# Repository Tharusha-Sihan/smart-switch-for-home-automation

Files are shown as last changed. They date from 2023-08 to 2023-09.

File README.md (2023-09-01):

# Smart Switch for Home Automation
This is an ESP32-based smart switch project designed to address the requirement for a convenient method to automate regular home appliances, especially in compact spaces like individual rooms. 

<p align="center">

</p>

## Reqirements
The followings were considered as the basic needs that should be satisfied by the solution.
  +	Should be able to control remotely.
  +	Should be compatible with existing home appliances.
  +	Should be able to install easily.
  +	Compatible with industry standards.
  +	Durable and reliable.
  +	should be cost effective.
  
In addition to that following features were intended to be integrated.
  +	Device can be controlled manually as well as remotely through internet and physical buttons.
  +	The device can be connected to any Wi-Fi network without hard coding. Which is a necessity for a consumer IoT device.
  +	Fits into the conventional sunk boxes and can be powered using domestic AC supply.
  +	Can control multiple appliances from one device.
  +	Users can connect the device to a new Wi-Fi network, switch appliances, set timers and monitor using a web interface or mobile app.
  
## Implementation
Considering its in-built WiFi connectivity, impressive processing power and the memory capacity, ESP32 microcontroller is selected as the central control unit of this embedded IoT project. Inbuild capacitive touch sensors of ESP32 were utilized as physical touch buttons. the design files of first prototype can be accessed in [version-01 folder.](version-01/)

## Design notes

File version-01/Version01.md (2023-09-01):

# version- 01
<p  float="left">
  
  
  </p>

## Block Diagram
<p  align="center">

</p>

## component selection
After comparing several alternatives, the following components were selected. Their performance, price, availability and reliability were mainly concerned.
+ **ESP32 WROOM 32D :** The ESP32 microcontroller is chosen for its processing capabilities and built-in WIFI connectivity. It offers sufficient computing power to manage the device and efficiently transmit data to the servers. Moreover, the ESP32’s ability to connect with nearby WIFI access points allows for seamless web integration. [Datasheet](https://www.mouser.com/datasheet/2/891/esp-wroom-32_datasheet_en-1223836.pdf)
+ **HLK-PM-03 :** To convert 230V AC supply into 3.3V DC HLK-PM-03 module is chosen due to its compact size, versatility, high reliability, energy efficiency, and ease of integration. This module boasts a remarkably small form factor, making it an ideal choice for space-constrained applications. It is designed for high energy efficiency which aligns perfectly with our goals.[Datasheet](https://datasheet.lcsc.com/szlcsc/1909111105_HI-LINK-HLK-PM24_C399250.pdf)
+ **Mechanical relays :** Despite the relatively low reliability compared to the solid-state relays mechanical relays were chosen due to their low cost.
+ **BS170 :** n-channel MOSFET is chosen for switching relays. It has a high current capacity.[Datasheet](https://www.onsemi.com/pdf/datasheet/mmbf170-d.pdf)
+ **Pull-up Resistors and Capacitors :** The selected pull-up resistors and capacitors are determined based on the ESP32 chip’s data sheet to ensure proper communication and programming.

### BoM
  
| Component | Quantity |
| --- | ---|
| ESP32 WROOM 32d | 1 |
|HLK-PM-03 | 1 |
|SRD 3V relay | 3 |
|Varistors 180pF 560volts 10% | 1 |
|Safety Capacitors 275VAC 0.1uF |	1 |
|BS170 n-channel MOSFET	|3|
|push buttonn |	2|
|10kOhm resistors 0805 pkg|	5|
|10uF - tantalum - 3216 mm	|1|
|0.1uF - 0805 pkg	|1|
|220uF - electrolyte|	1|
|100uF (extra) electrolyte|	1|
|1kOhm resistors 0805 pkg	|3|
|3ways terminal blocks 5.08 pitch|	1|
|2 ways terminal block 5.08 pitch|	1|
|3 pin JST connectors|	1|
|4 pin male headers|	1|

## Schematic Design
<p align="center">


</p>

## PCB Layout
<p align="center">

</p>

### Top Layer
<p align="center">
<img width ="55%" src=https://github.com/Tharusha-Sihan/smart-switch-for-home-automation/assets/116502446/feddea3c-755d-482b-a493-c083f2a8d2b6"/>
</p>

### Bottom Layer
<p align="center">

</p>

## Enclosure
Initial enclosure design is as follows. 
<p align="center">

</p>

After considering expandability, manufacturability and esthetics aspects initial designs were revised.

<p float="left">


</p>

## Interface
The user interface is designed with a seamless blend of touch buttons for manual control and a user-friendly web page for remote access and network configuration. 
<p align="center">

</p>

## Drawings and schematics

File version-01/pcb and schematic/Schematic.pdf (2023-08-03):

# Power Supply

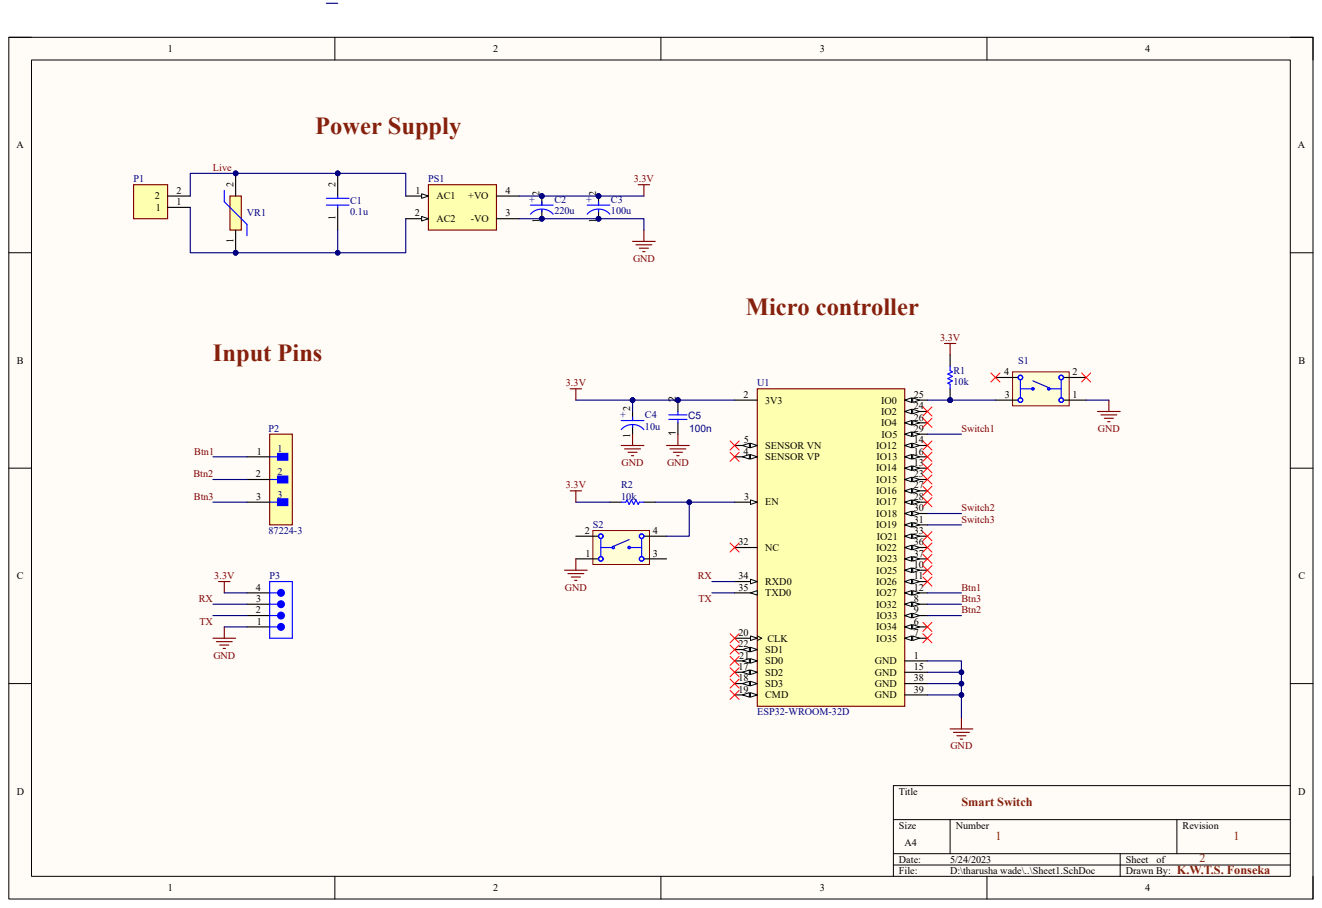
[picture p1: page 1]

# Switches

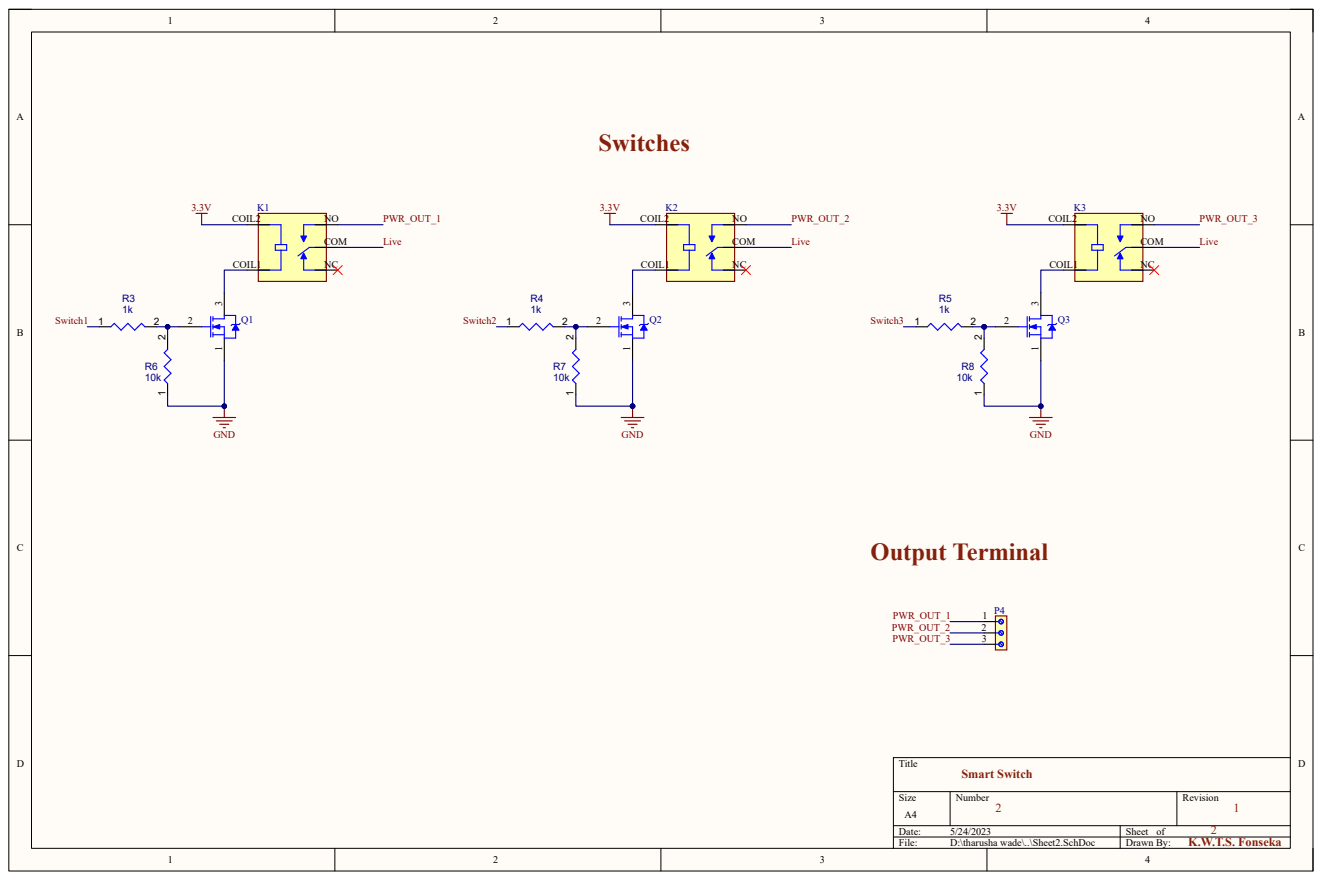
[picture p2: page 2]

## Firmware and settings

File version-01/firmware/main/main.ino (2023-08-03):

#include <Arduino.h>
#include <WiFi.h>
#include <ESPAsyncWebServer.h>
#include <AsyncTCP.h>
#include "SPIFFS.h"


int threshold = 20;

unsigned long last_pressed = millis();
int button_delay = 200;
int relay_state[3] = {};
int relay[] = {5, 18, 19};
int button[] = {27, 33, 32};

void gotTouch1() {
  if ( millis() - last_pressed > button_delay) {
    last_pressed = millis();
    relay_state[0] = !relay_state[0];
    for (int i = 0; i < 3; i++) {
      Serial.print(touchRead(button[i]));
      Serial.print(" ");
    }
    for (int i = 0; i < 3; i++) {
      Serial.print(relay_state[i]);
      Serial.print(" ");
    }
  }
}

void gotTouch2() {
  if ( millis() - last_pressed > button_delay) {
    last_pressed = millis();
    relay_state[1] = !relay_state[1];
    for (int i = 0; i < 3; i++) {
      Serial.print(touchRead(button[i]));
      Serial.print(" ");
    }
    for (int i = 0; i < 3; i++) {
      Serial.print(relay_state[i]);
      Serial.print(" ");
    }
  }
}

void gotTouch3() {
  if ( millis() - last_pressed > button_delay) {
    last_pressed = millis();
    relay_state[2] = !relay_state[2];
    for (int i = 0; i < 3; i++) {
      Serial.print(touchRead(button[i]));
      Serial.print(" ");
    }
    Serial.print(" | ");
    for (int i = 0; i < 3; i++) {
      Serial.print(relay_state[i]);
      Serial.print(" ");
    }
    Serial.println("");
  }
}

void set_relay() {
  for (int i = 0; i < 3; i++) {
    digitalWrite(relay[i], relay_state[i]);
  }
}

// Create AsyncWebServer object on port 80
AsyncWebServer server(80);

// Search for parameter in HTTP POST request
const char* PARAM_INPUT_1 = "ssid";
const char* PARAM_INPUT_2 = "pass";
const char* PARAM_INPUT_3 = "ip";
const char* PARAM_INPUT_4 = "gateway";
bool switch1state = true;


//Variables to save values from HTML form
String ssid;
String pass;
String ip;
String gateway;

// File paths to save input values permanently
const char* ssidPath = "/ssid.txt";
const char* passPath = "/pass.txt";
const char* ipPath = "/ip.txt";
const char* gatewayPath = "/gateway.txt";

IPAddress localIP;
//IPAddress localIP(192, 168, 1, 200); // hardcoded

// Set your Gateway IP address
IPAddress localGateway;
//IPAddress localGateway(192, 168, 1, 1); //hardcoded
IPAddress subnet(255, 255, 225, 240);

// Timer variables
unsigned long previousMillis = 0;
const long interval = 10000;  // interval to wait for Wi-Fi connection (milliseconds)

// Set LED GPIO
const int ledPin = 2;
// Stores LED state


// Initialize SPIFFS
void initSPIFFS() {
  if (!SPIFFS.begin(true)) {
    Serial.println("An error has occurred while mounting SPIFFS");
  }
  Serial.println("SPIFFS mounted successfully");
}

// Read File from SPIFFS
String readFile(fs::FS &fs, const char * path) {
  Serial.printf("Reading file: %s\r\n", path);

  File file = fs.open(path);
  if (!file || file.isDirectory()) {
    Serial.println("- failed to open file for reading");
    return String();
  }

  String fileContent;
  while (file.available()) {
    fileContent = file.readStringUntil('\n');
    break;
  }
  return fileContent;
}

// Write file to SPIFFS
void writeFile(fs::FS &fs, const char * path, const char * message) {
  Serial.printf("Writing file: %s\r\n", path);

  File file = fs.open(path, FILE_WRITE);
  if (!file) {
    Serial.println("- failed to open file for writing");
    return;
  }
  if (file.print(message)) {
    Serial.println("- file written");
  } else {
    Serial.println("- write failed");
  }
}

// Initialize WiFi
bool initWiFi() {
  if (ssid == "" || ip == "") {
    Serial.println("Undefined SSID or IP address.");
    return false;
  }

  WiFi.mode(WIFI_STA);
  localIP.fromString(ip.c_str());
  localGateway.fromString(gateway.c_str());


  if (!WiFi.config(localIP, localGateway, subnet)) {
    Serial.println("STA Failed to configure");
    return false;
  }
  WiFi.begin(ssid.c_str(), pass.c_str());
  Serial.println("Connecting to WiFi...");

  unsigned long currentMillis = millis();
  previousMillis = currentMillis;

  while (WiFi.status() != WL_CONNECTED) {
    currentMillis = millis();
    if (currentMillis - previousMillis >= interval) {
      Serial.println("Failed to connect.");
      return false;
    }
  }

  Serial.println(WiFi.localIP());
  return true;
}

void setup() {
  for (int i = 0; i < 3; i++) {
    pinMode(relay[i], OUTPUT);
  }
  // Serial port for debugging purposes
  Serial.begin(115200);
  touchAttachInterrupt(button[0], gotTouch1, threshold);
  touchAttachInterrupt(button[1], gotTouch2, threshold);
  touchAttachInterrupt(button[2], gotTouch3, threshold);

  initSPIFFS();

  // Set GPIO 2 as an OUTPUT
  pinMode(ledPin, OUTPUT);
  digitalWrite(ledPin, LOW);

  // Load values saved in SPIFFS
  ssid = readFile(SPIFFS, ssidPath);
  pass = readFile(SPIFFS, passPath);
  ip = readFile(SPIFFS, ipPath);
  gateway = readFile (SPIFFS, gatewayPath);
  Serial.println(ssid);
  Serial.println(pass);
  Serial.println(ip);
  Serial.println(gateway);

  if (!(initWiFi())) {
    Serial.println("Setting AP (Access Point)");
    // NULL sets an open Access Point
    WiFi.mode(WIFI_AP_STA);
    WiFi.softAP("Smart-Hub", NULL);

    delay(2000);
    // Set static IP
    IPAddress AP_LOCAL_IP(192, 168, 1, 200);
    IPAddress AP_GATEWAY_IP(192, 168, 1, 4);
    IPAddress AP_NETWORK_MASK(255, 255, 255, 0);
    if (!WiFi.softAPConfig(AP_LOCAL_IP, AP_GATEWAY_IP, AP_NETWORK_MASK)) {
      Serial.println("AP Config Failed");
      return;
    }
    // Show the local IP
    Serial.print("AP IP address: ");
    IPAddress IP = WiFi.softAPIP();
    Serial.println(IP);
  }
  server.on("/", HTTP_GET, [](AsyncWebServerRequest * request) {
    request->send(SPIFFS, "/wifimanager.html", "text/html");
  });

  server.serveStatic("/", SPIFFS, "/");

  // toggle switch 1
  server.on("/toggleswitch1", HTTP_GET, [](AsyncWebServerRequest * request) {

    relay_state[0] = !relay_state[0];

    request->send(200, "text/plain", String(relay_state[0]));
    //delay(3000);
  });

  // toggle switch 2
  server.on("/toggleswitch2", HTTP_GET, [](AsyncWebServerRequest * request) {

    relay_state[1] = !relay_state[1];

    request->send(200, "text/plain", String(relay_state[1]));
    //delay(3000);
  });

  // toggle switch 3
  server.on("/toggleswitch3", HTTP_GET, [](AsyncWebServerRequest * request) {

    relay_state[2] = !relay_state[2];

    request->send(200, "text/plain", String(relay_state[2]));
    //delay(3000);
  });

  // get switch 1 status
  server.on("/getSwitch1Status", HTTP_GET, [](AsyncWebServerRequest * request) {
    request->send(200, "text/plain", String(relay_state[0]));
    //delay(3000);
  });

  // get switch 2 status
  server.on("/getSwitch2Status", HTTP_GET, [](AsyncWebServerRequest * request) {
    request->send(200, "text/plain", String(relay_state[1]));
    //delay(3000);
  });

  // get switch 3 status
  server.on("/getSwitch3Status", HTTP_GET, [](AsyncWebServerRequest * request) {
    request->send(200, "text/plain", String(relay_state[2]));
    //delay(3000);
  });

  server.on("/", HTTP_POST, [](AsyncWebServerRequest * request) {
    int params = request->params();
    for (int i = 0; i < params; i++) {
      AsyncWebParameter* p = request->getParam(i);
      if (p->isPost()) {
        // HTTP POST ssid value
        if (p->name() == PARAM_INPUT_1) {
          ssid = p->value().c_str();
          Serial.print("SSID set to: ");
          Serial.println(ssid);
          // Write file to save value
          writeFile(SPIFFS, ssidPath, ssid.c_str());
        }
        // HTTP POST pass value
        if (p->name() == PARAM_INPUT_2) {
          pass = p->value().c_str();
          Serial.print("Password set to: ");
          Serial.println(pass);
          // Write file to save value
          writeFile(SPIFFS, passPath, pass.c_str());
        }
        // HTTP POST ip value
        if (p->name() == PARAM_INPUT_3) {
          ip = p->value().c_str();
          Serial.print("IP Address set to: ");
          Serial.println(ip);
          // Write file to save value
          writeFile(SPIFFS, ipPath, ip.c_str());
        }
        // HTTP POST gateway value
        if (p->name() == PARAM_INPUT_4) {
          gateway = p->value().c_str();
          Serial.print("Gateway set to: ");
          Serial.println(gateway);
          // Write file to save value
          writeFile(SPIFFS, gatewayPath, gateway.c_str());
        }
        //Serial.printf("POST[%s]: %s\n", p->name().c_str(), p->value().c_str());
      }
    }
    request->send(200, "text/plain", "Done. ESP will restart, connect to your router and go to IP address: " + ip);
    delay(3000);
    ESP.restart();
  });
  server.begin();
}

void loop() {

  set_relay();
  delay(100);
}
